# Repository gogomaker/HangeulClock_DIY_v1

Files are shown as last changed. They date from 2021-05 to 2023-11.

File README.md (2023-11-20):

# HangeulClock_DIY_v1
이호민 작가님의 한글시계 따라 만들기

WoW!

재미있는 한글시계 만들기!

# 한글시계란

한글시계란, 이호민 작가님이 만드신 시계로서, 기존의 시간표시방식과 다르게, 한글로 시간을 볼 수 있습니다.

특히, 인테리어 용으로, 시계를 잘 보지 못하는 아이들이 직관적으로 볼 수 있습니다.

# 만들게 된 동기

생계형 메이커인 나, 어느 날 웹서핑을 하다가 한글시계를 발견한다. 너무 얘쁘고 사서 내 방에 뙇 놔두고 싶은데, 문제는...

너무나도 비싼 가걱에 지갑씨가 거절해 버렸다...

할 수 없이 나는 직접 만들기로 하는데...

# 기능
1. 시간을 한글로 표시해 준다
2. LED의 밝기및 색상을 조절할 수 있다

# 제작과정
시계의 앞판은 https://hangulclock.today/ 이 링크의 배열을 본따 만들었으며, 모든 디자인은 fusion 360 에서 직접 디자인하였고, 코딩은 VS에서 진행하다가 잠시 Arduino IDE로 옮겼다가 후에 VScode에서 진행하였습니다.

사실 정확한 개발일지가 없어서(ㅜ.ㅜ) 기억이 가물가물하네요...

2020.06 경 - 제작시작

2020.10 경 - 1차 기능개발 완료(시계기능 구현)

2020.12 경 - 2차 기능개발 완료(LED밝기 및 색깔 제어 기능 구현)

2021.01 경 - 추가적 기능 보수 및 에러 보수, 모든 에러 다 잡음.

2021.05.24 - github을 알게 되고 처음 커밋 함

2021.05.31 - 기존에는 메인 파일과 함수를 2개의 .ino로 나누어 그냥 작업을 했었는데(아두이노 IDE의 경우 문제없이 작동을 한다.) git을 사용하기 위해 VScode를 사용하려 하자, 앞의 방식이 오류를 일으켜 함수를 저장한 .ino 파일을 헤더파일로 바꿈.

- 개발완료 -

2021-06-24: 오늘은 내 옛 노트북을 사용할 수 있게 설정한다고 바뻤다. 
오늘, 옛 노트북에 이 프로젝트를 연동시켜 놓았다.
앞으로는, git push뿐 아니라 git pull도 잘 연습할 수 있을 것 같다.

# 앞으로의 계획
앞으로는, 이 프로젝트를 이어 가는 것이 아닌, 프로젝트 이름 처럼 v1에서 v2로 넘어갈 것이다,.

고로 이놈의 개발은 끝났다 ! 

### v2 에서 만나요~

# 다시 시작하는 개발일지
이 디자인의 시계를 "누구나" 사용할 수 있도록 다시 만들어야 할 필요성이 생겼다. 따라서, 이 프로젝트를 다시 시작할 예정이다. 

2023-11-20 Mon \
오늘은, 초기화한 노트북에 이 레포지토리를 연동하고, 프로젝트를 제정비하였다. 레거시 아두이노를 설치한다는 것이 아두이노 IDE를 설치했더니, 라이브러리 디렉토리가 꼬여서 VScode가 난리를 친다. 이래서 검증된 것만 해야 하나보다. \
각설하고, 이제부터, 이 레포지토리의 코드와 자료들 다 갈아엎고 새롭게 시작할 거다. 기존의 디자인도 아마 원형만 남겨두고 갈아엎게 되지 않을까 싶다. 코드는 핵심 기능만 남기고 조금 더 효율적으로 바꾸게 될 듯 하다.

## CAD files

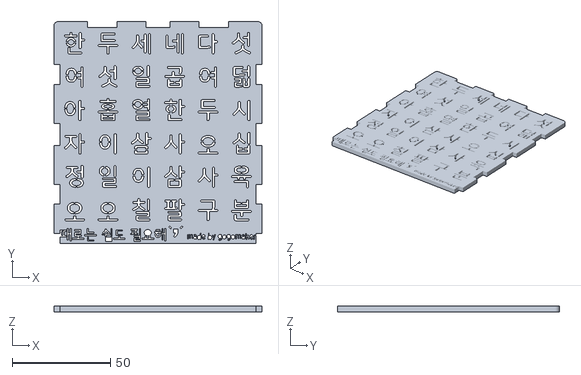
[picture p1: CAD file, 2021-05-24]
Design/clock_panel.stl
106.0 x 113.0 x 3.00

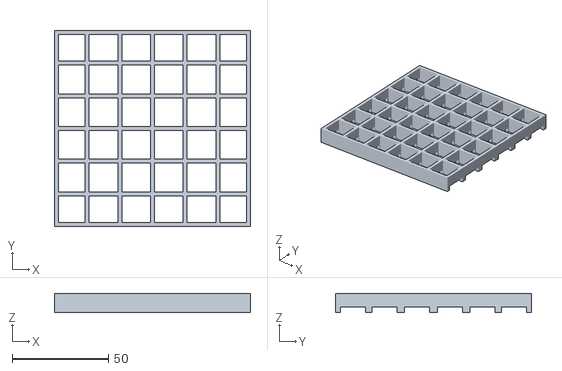
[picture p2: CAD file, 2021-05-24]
Design/partition.stl
102.0 x 102.0 x 10.0

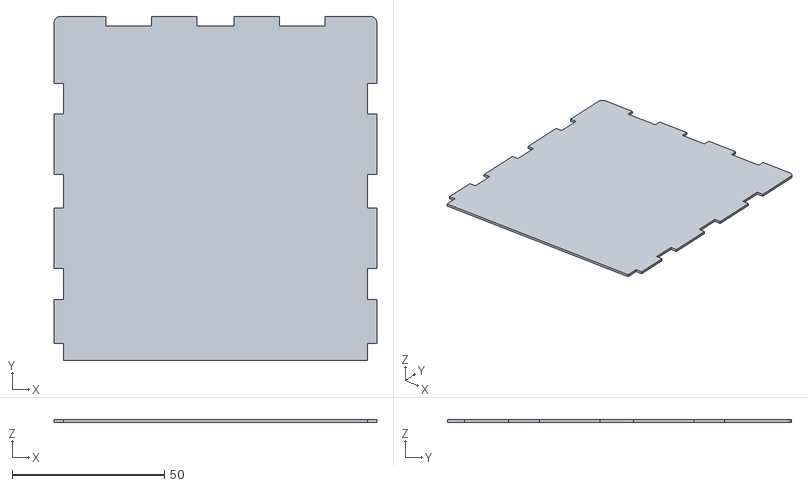
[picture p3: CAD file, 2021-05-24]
Design/Diffuser.stl
106.0 x 113.0 x 1.00

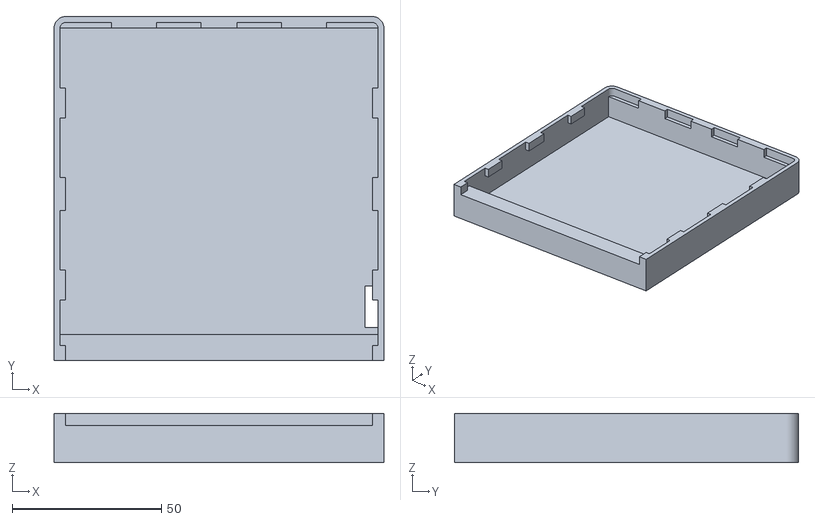
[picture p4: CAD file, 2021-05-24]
Design/body.stl
110.6 x 115.3 x 16.5

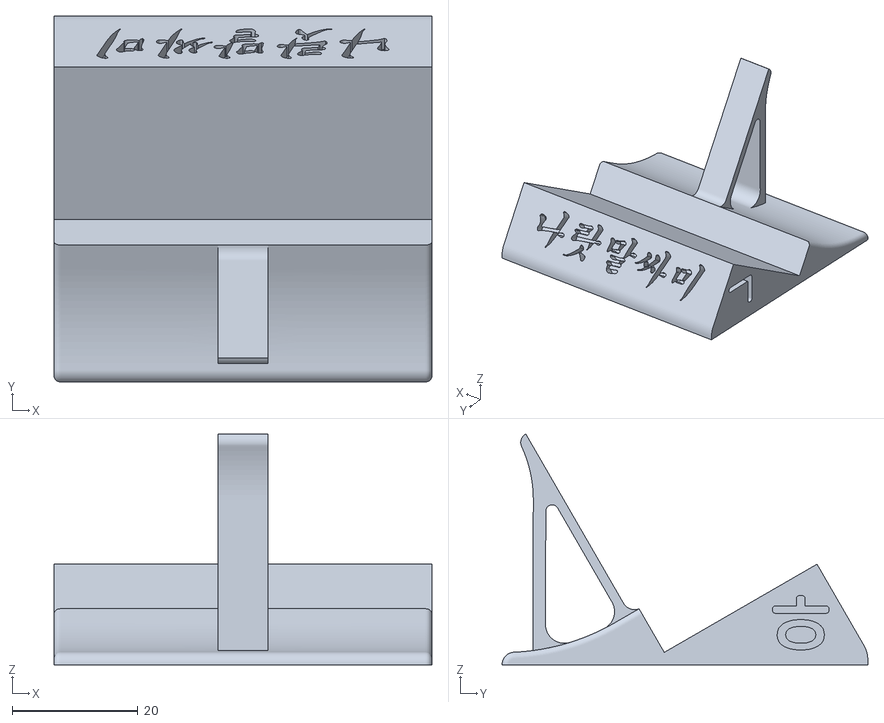
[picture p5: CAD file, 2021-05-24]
Design/stand.stl
60.0 x 58.1 x 36.7

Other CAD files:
Design/clock_panel.dxf

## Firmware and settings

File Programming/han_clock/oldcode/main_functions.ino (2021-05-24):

void displayTime(int h, int m) {
	ledclear();
	if (!((h == 0 || h == 12) && m == 0)) {
		updateHour(h);
		updateMin(m);
	}
	else {
		if (h == 0) {
			printled(17);
			printled(6);
		}
		else {
			printled(6);
			printled(5);
		}
	}
	strip.show();
}

int updateHour(int h) {
	printled(23);
	if (h == 0 || h == 12) { printled(20); printled(22); }
	else if (h == 1 || h == 13) { printled(30); }
	else if (h == 2 || h == 14) { printled(31); }
	else if (h == 3 || h == 15) { printled(32); }
	else if (h == 4 || h == 16) { printled(33); }
	else if (h == 5 || h == 17) { printled(34); printled(35); }
	else if (h == 6 || h == 18) { printled(29); printled(28); }
	else if (h == 7 || h == 19) { printled(27); printled(26); }
	else if (h == 8 || h == 20) { printled(25); printled(24); }
	else if (h == 9 || h == 21) { printled(18); printled(19); }
	else if (h == 10 || h == 22) printled(20);
	else if (h == 11 || h == 23) { printled(20); printled(21); }
}

int updateMin(int m) {
	if(m) printled(0);
	int ten = m / 10;
	if      (ten == 1) { printled(12); printled(0); }
	else if (ten == 2) { printled(12); printled(16); }
	else if (ten == 3) { printled(12); printled(15); }
	else if (ten == 4) { printled(12); printled(14); }
	else if (ten == 5) { printled(12); printled(13); }

	m -= ten * 10;
	if      (m == 1) printled(7);
	else if (m == 2) printled(8);
	else if (m == 3) printled(9);
	else if (m == 4) printled(10);
	else if (m == 5) printled(4);
	else if (m == 6) printled(11);
	else if (m == 7) printled(3);
	else if (m == 8) printled(2);
	else if (m == 9) printled(1);
}

void printled(int n) {
	if (ledmode == 0) {
		randomBase++;
		randomSeed(randomBase);
		byte rand = random(0, 12);
		r = color[rand][0];
		g = color[rand][1];
		b = color[rand][2];
	}
	strip.setPixelColor(n, r, g, b);
}

void ledclear() {
	for (int i = 0; i < strip.numPixels(); i++) {
		strip.setPixelColor(i, 0, 0, 0);
	}
	strip.show();
}

void changeTimeButton() {
	int reading = digitalRead(2);
	if (reading != last_bu_state[0]) {
		LastDebounceTime[0] = time;
	}
	if ((time - LastDebounceTime[0]) > debounceDelay) {
		if (reading != bu_state[0]) {
			bu_state[0] = reading;
			if (bu_state[0] == LOW) {
				//Serial.println("Time_pressed");
				bu_t_w = time;
				timeCheck = true;
			}
			else {
				if (time < bu_t_w + bu_interval) {
					if (tchange == 1) {
						//Serial.println("hour plus");
						hourPlus++;
						if (hourPlus > 23) hourPlus = 0;
						hour = (hourRtc + hourPlus) % 24;
						displayTime(hour, min);
					}
					else if(tchange == 2) {
						//Serial.println("min plus");
						minPlus++;
						if (minPlus > 59) minPlus = 0;
						min = (minRtc + minPlus) % 60;
						displayTime(hour, min);
					}
					timeCheck = false;
				}
			}
		}
	}
	last_bu_state[0] = reading;
}

void changeLedButton() {
	int reading = digitalRead(3);
	if (reading != last_bu_state[1]) {
		LastDebounceTime[1] = time;
	}
	if ((time - LastDebounceTime[1]) > debounceDelay) {
		if (reading != bu_state[1]) {
			bu_state[1] = reading;
			if (bu_state[1] == LOW) {
				//Serial.println("LED_pressed");
				bu_led_w = time;
				ledCheck = true;
			}
			else {	//�����ٸ�
				if (time < bu_led_w + bu_interval) {
					bright += 30;
					if (bright > 210) bright = 30;
					strip.setBrightness(bright);
					displayTime(hour, min);
					//Serial.print("change brightness: ");
					//Serial.println(bright);
					ledCheck = false;
				}
			}
		}
	}
	last_bu_state[1] = reading;
}

void longTimeButton() {
	if (timeCheck == true) {
		if ((time - bu_t_w) >= bu_interval) {
			tchange += 1;
			if (tchange > 2) tchange = 0;
			if (tchange == 1) {
				//Serial.println("hour off");
				wait_t = time;
				if ((hour == 0 || hour == 12) && min == 0) {
					printled(23);
					strip.show();
				}
				else {
					strip.setPixelColor(23, 0, 0, 0);
					strip.show();
				}
				isblinkH = true;
			}
			else if (tchange == 2) {
				//Serial.println("min off");
				wait_m = time;
				if (min == 0) {
					printled(0);
					strip.show();
				}
				else {
					strip.setPixelColor(0, 0, 0, 0);
					strip.show();
				}
				isblinkM = true;
			}
			timeCheck = false;
			//Serial.print("mode change: ");
			//Serial.println(tchange);
		}
	}
}

void longLedButton() {
	if (ledCheck == true) {
		if ((time - bu_led_w) >= bu_interval) {
			//Serial.println("change color");
			ledmode++;
			if (ledmode > 12) ledmode = 0;
			if (ledmode > 0) {
				r = color[ledmode][0];
				g = color[ledmode][1];
				b = color[ledmode][2];
			}
			displayTime(hour, min);
			ledCheck = false;
		}
	}
}

byte decToBcd(byte val) {
	return ((val / 10 * 16) + (val % 10));
}

void set3231Date() {
	//year = (byte)((Serial.read() - 48) * 10 + (Serial.read() - 48));
	//month = (byte)((Serial.read() - 48) * 10 + (Serial.read() - 48));
	//date = (byte)((Serial.read() - 48) * 10 + (Serial.read() - 48));
	//hour = (byte)((Serial.read() - 48) * 10 + (Serial.read() - 48));
	//min = (byte)((Serial.read() - 48) * 10 + (Serial.read() - 48));
	//sec = (byte)((Serial.read() - 48) * 10 + (Serial.read() - 48));
	//day = (byte)(Serial.read() - 48);
	if (!min) hour++;
	Wire.beginTransmission(DS3231_I2C_ADDRESS);
	Wire.write(0x00);
	Wire.write(sec);
	Wire.write(decToBcd(min));
	Wire.write(decToBcd(hour));
	//Wire.write(decToBcd(day));
	//Wire.write(decToBcd(date));
	//Wire.write(decToBcd(month));
	//Wire.write(decToBcd(year));
	Wire.endTransmission();

	minPlus = hourPlus = 0;
}

void get3231Date() {
	// send request to receive data starting at register 0
	Wire.beginTransmission(DS3231_I2C_ADDRESS); // 104 is DS3231 device address
	Wire.write(0x00); // start at register 0
	Wire.endTransmission();
	Wire.requestFrom(DS3231_I2C_ADDRESS, 7); // request seven bytes

	if (Wire.available()) {
		sec = Wire.read(); // get seconds
		minRtc = Wire.read(); // get minutes
		hourRtc = Wire.read();   // get hours
	//	day = Wire.read();
	//	date = Wire.read();
	//	month = Wire.read(); //temp month
	//	year = Wire.read();

		sec = (((sec & B11110000) >> 4) * 10 + (sec & B00001111)); // convert BCD to decimal
		minRtc = (((minRtc & B11110000) >> 4) * 10 + (minRtc & B00001111)); // convert BCD to decimal
		hourRtc = (((hourRtc & B00110000) >> 4) * 10 + (hourRtc & B00001111)); // convert BCD to decimal (assume 24 hour mode)
	//	day = (day & B00000111); // 1-7
	//	date = (((date & B00110000) >> 4) * 10 + (date & B00001111)); // 1-31
	//	month = (((month & B00010000) >> 4) * 10 + (month & B00001111)); //msb7 is century overflow
	//	year = (((year & B11110000) >> 4) * 10 + (year & B00001111));
	}
	else {
		//oh noes, no data!
	}

	/*switch (day) {
	case 1:
		strcpy(weekDay, "Sun");
		break;
	case 2:
		strcpy(weekDay, "Mon");
		break;
	case 3:
		strcpy(weekDay, "Tue");
		break;
	case 4:
		strcpy(weekDay, "Wed");
		break;
	case 5:
		strcpy(weekDay, "Thu");
		break;
	case 6:
		strcpy(weekDay, "Fri");
		break;
	case 7:
		strcpy(weekDay, "Sat");
		break;
	}*/
}

float get3231Temp() {
	//temp registers (11h-12h) get updated automatically every 64s
	Wire.beginTransmission(DS3231_I2C_ADDRESS);
	Wire.write(0x11);
	Wire.endTransmission();
	Wire.requestFrom(DS3231_I2C_ADDRESS, 2);

	if (Wire.available()) {
		tMSB = Wire.read(); //2's complement int portion
		tLSB = Wire.read(); //fraction portion

		temp3231 = (tMSB & B01111111); //do 2's math on Tmsb
		temp3231 += ((tLSB >> 6) * 0.25); //only care about bits 7 & 8
	}
	else {
		//error! no data!
	}
	return temp3231;
}

void blinkHM() {
	if (isblinkH == true) {
		if (time >= wait_t + 300) {
			//Serial.println("hour on");
			if ((hour == 0 || hour == 12) && min == 0) {
				strip.setPixelColor(23, 0, 0, 0);
				strip.show();
			}
			else {
				printled(23);
				strip.show();
			}
			isblinkH = false;
		}
	}
	if (isblinkM == true) {
		if (time >= wait_m + 300) {
			//Serial.println("min on");
			if (min == 0) {
				strip.setPixelColor(0, 0, 0, 0);
				strip.show();
			}
			else {
				printled(0);
				strip.show();
			}
			isblinkM = false;
		}
	}
}

void showSerialTime() {

	Serial.print(hour, DEC);
	Serial.print(":");
	Serial.print(min, DEC);
	Serial.print(":");
	Serial.print(sec, DEC);
	Serial.print(" - Temp: ");
	Serial.println(get3231Temp());

	Serial.print(hourRtc);
	Serial.print(", ");
	Serial.print(hourPlus);
	Serial.print(" ; ");
	Serial.print(minRtc);
	Serial.print(",");
	Serial.println(minPlus);
	Serial.println();
}

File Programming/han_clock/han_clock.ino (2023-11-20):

/*
 Name:		han_clock.ino
 Created:	2020-08-25 오후 5:32:32
 Author:	daseu
 
 Ver.2 - 모든 기능 구현...
*/

//헤더파일 선언
#include "src/functions.h"

//실제 변수 및 객체 선언
byte color[12][3]
{
  {255, 255, 255},
  {255, 0, 0},
  {255, 94, 0},
  {255, 187, 0},
  {255, 228, 0},
  {171, 242, 0},
  {29, 219, 22},
  {0, 84, 255},
  {1, 0, 255},
  {95, 0, 255},
  {255, 0, 221},
  {255, 0, 100}
};

Adafruit_NeoPixel strip(36, 6, NEO_GRB + NEO_KHZ800);

extern volatile unsigned long timer0_millis; //millis 오버플로우 대비 초기화
unsigned long time = 0;
byte sec, lastSec = 0;
byte hourPlus, minPlus = 0; //버튼이 눌릴 때 이곳에 값이 임시저장 됨
byte minRtc, hourRtc = 0; //RTC의 시간값이 저장됨
byte min, hour = 0;   //최종적으로 출력되는 시간값이 저장됨
bool isResetMillis = false;
byte tMSB, tLSB;  //RTC온도관련
float temp3231;
byte r = 255; //네오픽셀 Red
byte g = 255; //네오픽셀 Green
byte b = 255; //네오픽셀 Blue
byte bright = 180;  //255가 최대, 0이 최소, 7단계 제어
byte ledmode = 0; //12개의 색
long randomBase = 0;
unsigned long bu_led_w = 0;
bool ledCheck = false;
bool bu_reading[2] = { HIGH, HIGH };  //버튼의 실제 상태를 표현하는 변수
bool bu_state[2] = { HIGH, HIGH };  //체터링을 거른 버튼의 상태를 표현하는 변수
bool last_bu_state[2] = { HIGH, HIGH }; //마지막 버튼 상태
unsigned long LastDebounceTime[2] = { 0, 0};
unsigned long bu_t_w, last_bu_t_w = 0;  //시간 버튼이 언제 눌렸는가
unsigned long wait_t, wait_m = 0; //LED깜박일 때 사용
bool timeCheck = false;
bool isblinkH, isblinkM = false;
byte tchange = 0;


void setup() {
#if defined(__AVR_ATtiny85__) && (F_CPU == 16000000)
	clock_prescale_set(clock_div_1);
#endif
	Wire.begin();
	//시리얼 모니터
	Serial.begin(115200);
	Serial.println("Hangeul Clock has turn ON");
	Serial.println("Clock start");
	//네오픽셀 초기설정
	strip.begin();
	strip.show();
	strip.setBrightness(bright);
	//버튼입력설정
	pinMode(BUTTON_T, INPUT_PULLUP);
	pinMode(BUTTON_LED, INPUT_PULLUP);
	//시간출력
	time = millis();
	get3231Date();
	hour = (hourRtc + hourPlus) % 24;
	min = (minRtc + minPlus) % 60;
	displayTime(hour, min);
}

void loop() {
	time = millis();
	get3231Date();
	if (!sec && !minRtc && !hourRtc) {	//millis 초기화
		if(!timer0_millis) isResetMillis = true;
		if (isResetMillis == true) {
			//Serial.println("Timer reset");
			bu_led_w = 0;
			LastDebounceTime[0] = 0;
			LastDebounceTime[1] = 0;
			bu_t_w = 0;
			last_bu_t_w = 0;
			wait_t = 0;
			wait_m = 0;
			time = 0;
			timer0_millis = 0;
			isResetMillis = false;
		}
	}
	//매 초마다
	if (sec != lastSec) {
		hour = (hourRtc + hourPlus) % 24;
		min = (minRtc + minPlus) % 60;
		if (!sec) {	//매 0초마다(1분 간격으로)
			if (hourPlus || minPlus) {
				//Serial.println("RTC set");
				set3231Date();
			}
			displayTime(hour, min);
			//Serial.println("updated");
		}
		lastSec = sec;
	}

	//버튼 눌림 감지 함수
	changeTimeButton();
	changeLedButton();
	//버튼 길게 눌림 감지 함수
	longTimeButton();
	longLedButton();
	//시간 변경 시 LED깜박임
	blinkHM();
  
}

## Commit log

2021-05-26 Add .h and .cpp header files
    Delete functions.ino and replace header files. But, it has many errors-multiple definition-. So, I will fix this.
    [functions.h, main_functions.ino]
2023-11-20 project_reStart 다시 시작하는 V1 한글시계
